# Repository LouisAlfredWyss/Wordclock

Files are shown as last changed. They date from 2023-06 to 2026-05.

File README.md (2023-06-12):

# Wordclock
Description and code of my swissgerman Wordclock

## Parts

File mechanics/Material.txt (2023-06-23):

1 Raspberry Pi 3
1 MeanWell Schaltnetzteil 5V DC 4,0A
1 digitaler LED RGB NeoPixel Stripe, IP65 vergossen, 30 LEDs/m
1 Lochrasterplatine 15x20mm
2m Kupferlitze schwarz 0.75mm2
2m Kupferlitze rot 0.75mm2
2m Kupferlitze weiss 0.75mm2
1 MDF Holzplatte 500x500x20mm von Jumbo
2 Sperrholzplatte 500x500x4mm von Jumbo

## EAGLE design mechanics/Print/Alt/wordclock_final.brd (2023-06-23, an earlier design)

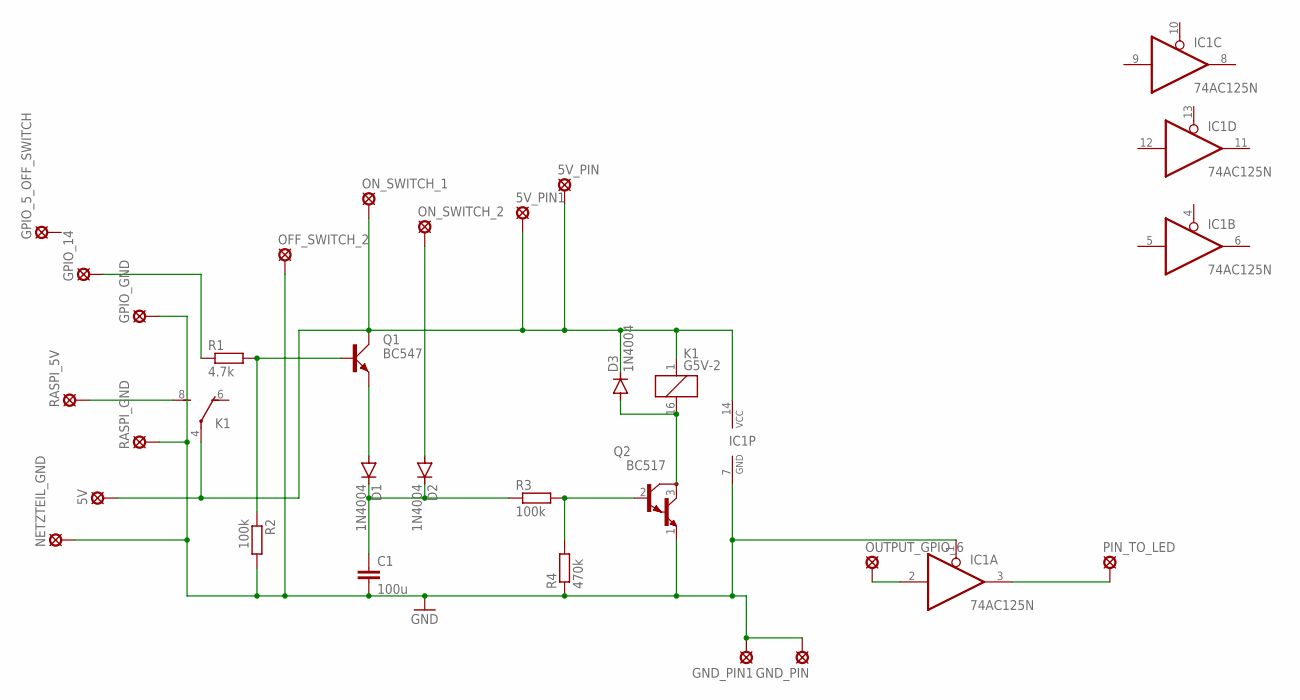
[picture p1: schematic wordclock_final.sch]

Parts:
5V, 5V_PIN, 5V_PIN1: SE14
C1: 100u; C025-060X050
D1, D2, D3: 1N4004; DO41-10
GND_PIN, GND_PIN1: SE14
GPIO_5_OFF_SWITCH, GPIO_14: SE14
GPIO_GND: SE14
IC1: 74AC125N; DIL14
K1: G5V-2
NETZTEIL_GND: SE14
OFF_SWITCH_2: SE14
ON_SWITCH_1, ON_SWITCH_2: SE14
OUTPUT_GPIO_6: SE14
PIN_TO_LED: SE14
Q1: BC547; SOT54A
Q2: BC517; TO92
R1: 4.7k; 0207/10
R2, R3: 100k; 0207/10
R4: 470k; 0207/10
RASPI_5V: SE14
RASPI_GND: SE14

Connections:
GND: C1.2, GND_PIN.MP, GND_PIN1.MP, GPIO_GND.MP, IC1.1 (OE), IC1.7 (GND), NETZTEIL_GND.MP, OFF_SWITCH_2.MP, Q2.1 (E), R2.2, R4.1, RASPI_GND.MP
unnamed: Q1.B, R1.2, R2.1
unnamed: D1.A, Q1.E
unnamed: D2.A, ON_SWITCH_2.MP
unnamed: IC1.2 (I), OUTPUT_GPIO_6.MP
unnamed: Q2.2 (B), R3.2, R4.2
unnamed: D3.A, K1.16 (2), Q2.3 (C)
unnamed: 5V.MP, 5V_PIN.MP, 5V_PIN1.MP, D3.C, IC1.14 (VCC), K1.1, K1.4, ON_SWITCH_1.MP, Q1.C
unnamed: C1.1, D1.C, D2.C, R3.1
unnamed: GPIO_14.MP, R1.1
unnamed: K1.8 (S), RASPI_5V.MP
unnamed: IC1.3 (O), PIN_TO_LED.MP

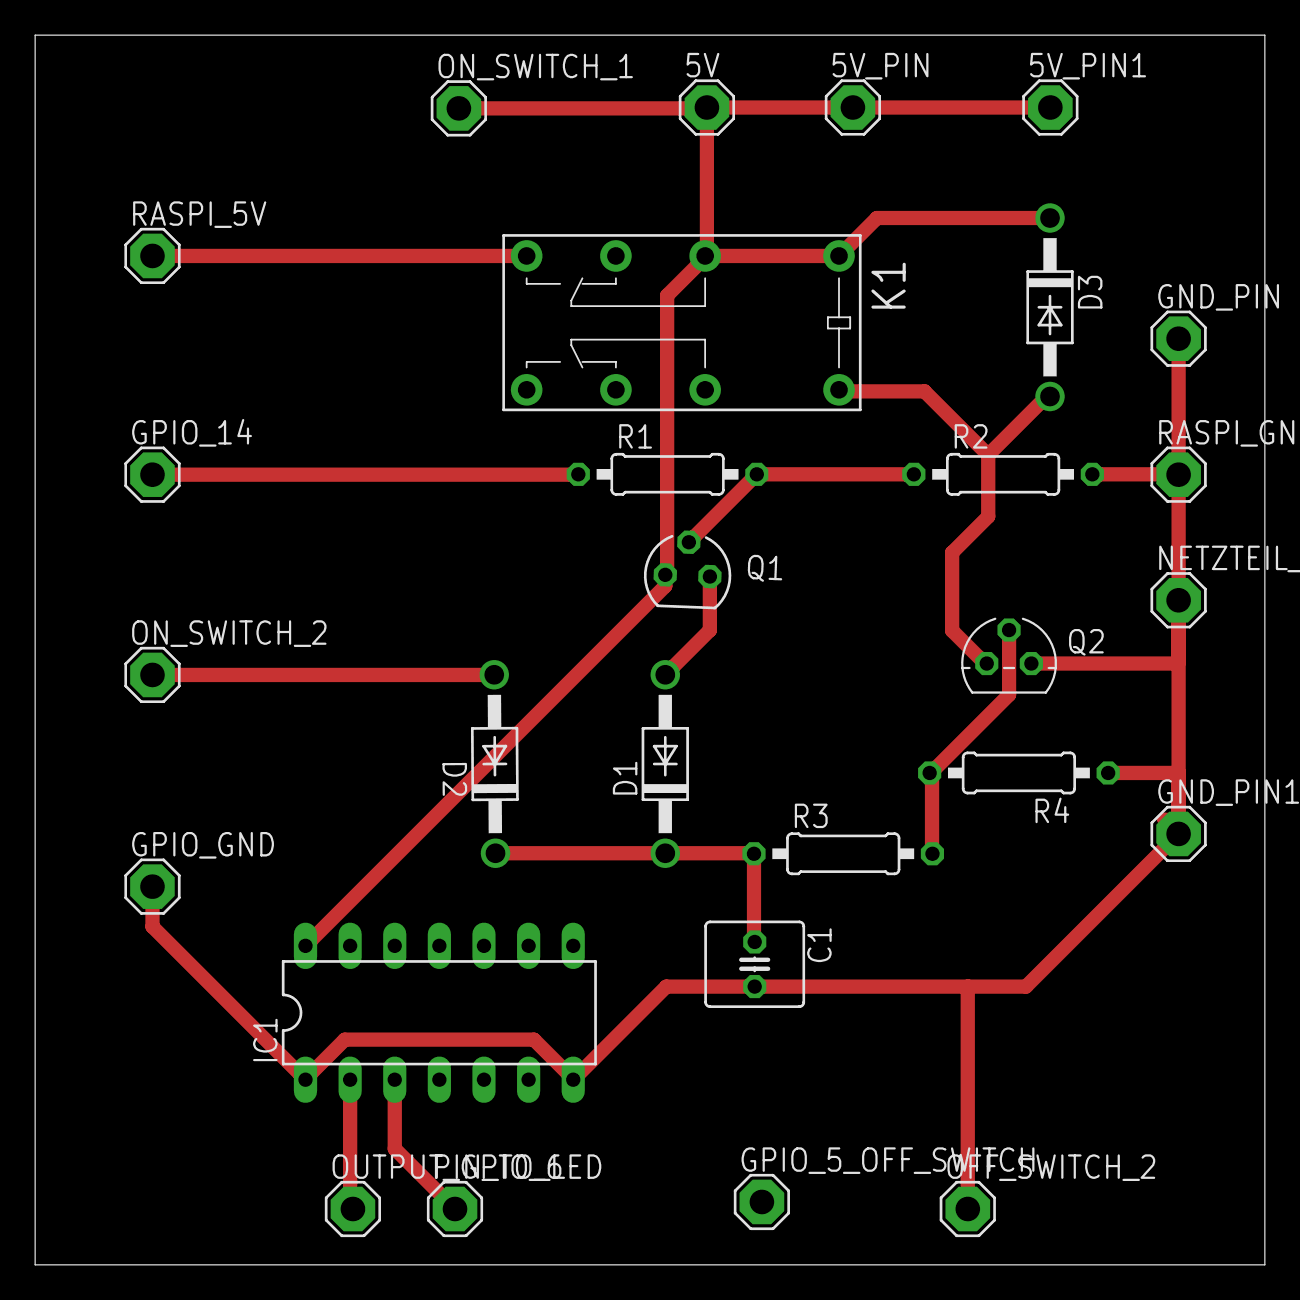
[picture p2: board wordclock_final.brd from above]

Board: 2 copper layers, 70.0 x 70.0 mm, 28 parts (0 on the bottom side), 12 nets.

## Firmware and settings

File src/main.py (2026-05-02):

# coding=utf-8
import argparse
from datetime import datetime
import numpy as np 
from rpi_ws281x import PixelStrip, Color
from led import set_color, clear_color, set_minute, wipe_color
from constants import LED_COUNT, LED_PIN, LED_FREQ_HZ, LED_DMA,\
                        LED_BRIGHTNESS, LED_INVERT, LED_CHANNEL
from constants import VEC_1, VEC_2, VEC_3, VEC_4, VEC_5, VEC_6, VEC_7,\
                        VEC_8, VEC_9, VEC_10, VEC_11, VEC_12, VEC_ES_ISCH

if __name__ == '__main__':
    # Process arguments
    parser = argparse.ArgumentParser()
    parser.add_argument('-c', '--clear', action='store_true', help='clear the display on exit')
    args = parser.parse_args()

    # Create NeoPixel object with appropriate configuration.
    strip = PixelStrip(LED_COUNT, LED_PIN, LED_FREQ_HZ, LED_DMA, LED_INVERT, LED_BRIGHTNESS, LED_CHANNEL)
    # Intialize the library (must be called once before other functions).
    strip.begin()
 
    print ('Press Ctrl-C to quit.')
    if not args.clear:
        print('Use "-c" argument to clear LEDs on exit')
 
    try:
        # "Es isch" anzeigen lassen, ist immer an.
        set_color(strip, VEC_ES_ISCH)
        
        while True:
            # time.sleep(1000/1000.0)
            
            # Abfragen der aktuellen Zeit und auf Stunden und Minuten aufteilen
            now_method = datetime.now()   
            hours = int(now_method.strftime("%H")) % 12
            minute = int(now_method.strftime("%M"))
            seconds = int(now_method.strftime("%S"))
            
            # Stunde um eines erhöhen wenn Minute grösser gleich 25
            if minute >= 25 and minute < 60:
                hours = hours +1

            # Abfragen, welche Stunde aktuell ist aktuelle Zeit anzeigen lassen
            if hours == 1:
                clear_color(strip, VEC_12)
                set_color(strip, VEC_1)
                set_minute(strip, minute)
                
            elif hours ==2:
                clear_color(strip, VEC_1)
                set_color(strip, VEC_2)
                set_minute(strip, minute)

            elif hours == 3:
                clear_color(strip, VEC_2)
                set_color(strip, VEC_3)
                set_minute(strip, minute)
                
            elif hours == 4:
                clear_color(strip, VEC_3)
                set_color(strip, VEC_4)
                set_minute(strip, minute)
                
            elif hours == 5:
                clear_color(strip, VEC_4)
                set_color(strip, VEC_5)
                set_minute(strip, minute)
                
            elif hours == 6:
                clear_color(strip, VEC_5)
                set_color(strip, VEC_6)
                set_minute(strip, minute)
                
            elif hours == 7:
                clear_color(strip, VEC_6)
                set_color(strip, VEC_7)
                set_minute(strip, minute)
                
            elif hours == 8:
                clear_color(strip, VEC_7)
                set_color(strip, VEC_8)
                set_minute(strip, minute)
                
            elif hours == 9:
                clear_color(strip, VEC_8)
                set_color(strip, VEC_9)
                set_minute(strip, minute)
                
            elif hours == 10:
                clear_color(strip, VEC_9)
                set_color(strip, VEC_10)
                set_minute(strip, minute)
                
            elif hours == 11:
                clear_color(strip, VEC_10)
                set_color(strip, VEC_11)
                set_minute(strip, minute)
                
            else:
                clear_color(strip, VEC_11)
                set_color(strip, VEC_12)
                set_minute(strip, minute)
            
 
    except KeyboardInterrupt:
        wipe_color(strip, Color(0,0,0), 0)
            

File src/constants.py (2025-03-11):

# File containing all constants to run the wordclock

import numpy as np

# LED strip configuration:
LED_COUNT      = 121      # Number of LED pixels.
LED_PIN        = 18      # GPIO pin connected to the pixels (18 uses PWM!).
#LED_PIN        = 10      # GPIO pin connected to the pixels (10 uses SPI /dev/spidev0.0).
LED_FREQ_HZ    = 800000  # LED signal frequency in hertz (usually 800khz)
LED_DMA        = 10      # DMA channel to use for generating signal (try 10)
LED_BRIGHTNESS = 100     # Set to 0 for darkest and 255 for brightest
LED_INVERT     = False   # True to invert the signal (when using NPN transistor level shift)
LED_CHANNEL    = 0       # set to '1' for GPIOs 13, 19, 41, 45 or 53

# Vektoren mit LED-Positionen zur jeweiligen Stunde
VEC_1 = [92, 104, 113]
VEC_2 = [5, 16, 27, 38]
VEC_3 = [3, 18, 25]
VEC_4 = [19, 24, 41, 46, 63]
VEC_5 = [1, 20, 23, 42]
VEC_6 = [60, 71, 82, 93, 103, 114]
VEC_7 = [0, 21, 22, 43, 44, 65]
VEC_8 = [66, 87, 88, 108, 109]
VEC_9 = [85, 90, 106, 111]
VEC_10 = [47, 62, 69, 84, 91]
VEC_11 = [17, 26, 39, 48]
VEC_12 = [64, 67, 86, 89, 107, 110]

# Vektor mit LED-Positionen zu den uebrigen Worten
VEC_ES_ISCH = [33, 54, 55, 76, 98, 119]
VEC_VOR = [14, 29, 36]
VEC_VIERTEL = [9, 12, 31, 34, 53, 56, 75]
VEC_UEBER = [58, 73, 80, 95]
VEC_HALBI = [15, 28, 37, 50, 59]
VEC_AB = [94 ,102]
VEC_FUEF = [97, 99, 118]
VEC_ZAEH = [96, 100, 117]
VEC_ZWAENZG = [13, 30, 35, 52, 57,74]

# Vekoren mit LED-Positionen zur jeweiligen Minute
VEC_5_10 = np.concatenate([VEC_FUEF, VEC_AB])
VEC_10_15 = np.concatenate([VEC_ZAEH, VEC_AB])
VEC_15_20 = np.concatenate([VEC_VIERTEL, VEC_AB])
VEC_20_25 = np.concatenate([VEC_ZWAENZG, VEC_AB])
VEC_25_30 = np.concatenate([VEC_FUEF, VEC_VOR, VEC_HALBI])
VEC_30_35 = VEC_HALBI
VEC_35_40 = np.concatenate([VEC_FUEF, VEC_UEBER, VEC_HALBI])
VEC_40_45 = np.concatenate([VEC_ZWAENZG, VEC_VOR])
VEC_45_50 = np.concatenate([VEC_VIERTEL, VEC_VOR])
VEC_50_55 = np.concatenate([VEC_ZAEH, VEC_VOR])
VEC_55_60 = np.concatenate([VEC_FUEF, VEC_VOR])

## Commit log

2023-06-23 First version of wordclock
    [copper_bottom.gbr, copper_top.gbr, drill_1_16.xln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]
2023-06-23 Materialliste erstellt
2023-07-27 Completly new version with API request to get temperature from mystrom switchs
2025-01-28 feature: organised folder structer new
    [copper_bottom.gbr, copper_top.gbr, drill_1_16.xln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]
2025-01-28 feature: Fixed code and clock is working again
    [constants.py, example.py, led.py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]
2025-03-11 Corrected mistake when time was :25
    [constants.py, main.py]
2026-05-02 FIX: Fix network issue
    [mystrom.py]
2026-05-02 FIX: Fixed ctrl+c error
    [main.py]
